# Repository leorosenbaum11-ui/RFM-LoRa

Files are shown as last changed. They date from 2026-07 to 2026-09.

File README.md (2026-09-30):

# RF-Messager-Project
Long range telemetry and communication through LoRa chip WIO-LR2021
PCB in 3d printed case with Keyboard, Screen, 2 SMA Antenna Ports, and GPS FL Antenna port

Part Models (more detailed BOM in files):
Microcontroller: Adafruit Feather ESP32-S3
Pin Extender: MCU23S17
Transciever: Seeed WIO-LR2021
Keyboard Driver: STM32F042CFU(x)
Keyboard: Solderparty Keebdeck Keyboard_6R13C
GPS: Adafruit Ultimate GPS MTK3339
Sensors: TI TMP-100 Temperature, MAX17048 Battery, BME280 Pressure Humidity
Compass: LSM303AGR Compass Accelerometer
Screen: ILI9341 Non-Touch

Program:
upload bbq10 firmware to stm32 and configure
upload my firmware

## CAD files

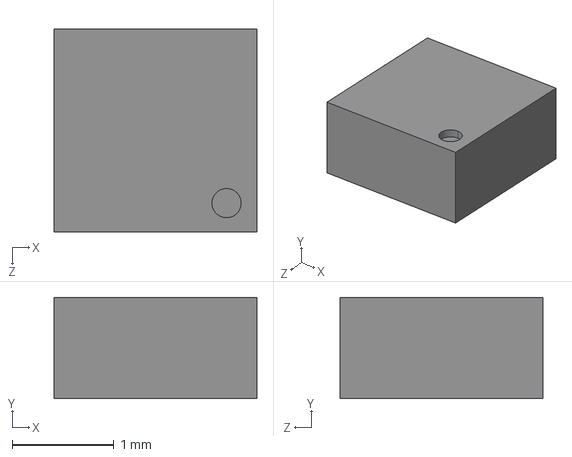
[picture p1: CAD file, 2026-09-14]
PCB Files/Footprint and Symbol Library/LSM303AGR/LSM303AGR.step
2.00 x 1.00 x 2.00 mm

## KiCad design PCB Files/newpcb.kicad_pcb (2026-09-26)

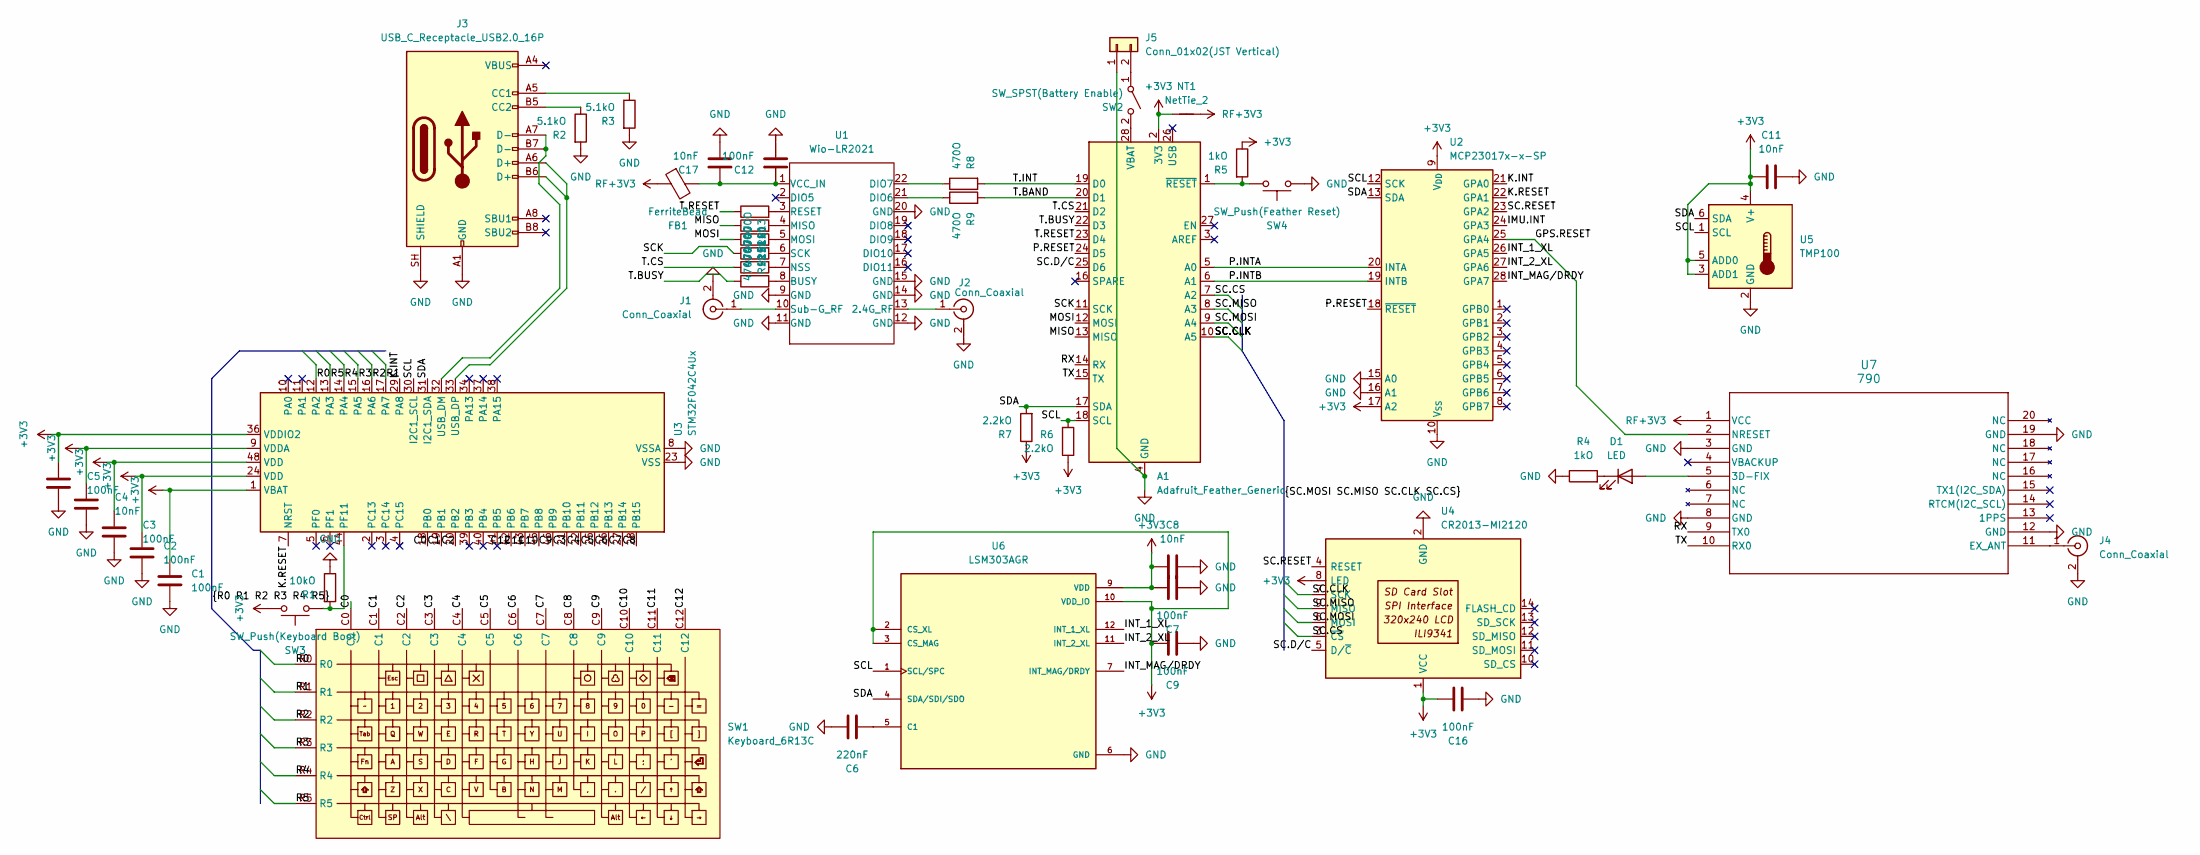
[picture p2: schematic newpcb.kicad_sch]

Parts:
A1: Adafruit_Feather_Generic; Adafruit_Feather
C1, C2, C3, C5, C7, C9, C12, C16: 100nF; C_0603_1608Metric_Pad1.08x0.95mm_HandSolder
C4, C8, C11, C17: 10nF; C_0603_1608Metric_Pad1.08x0.95mm_HandSolder
C6: 220nF; C_0603_1608Metric_Pad1.08x0.95mm_HandSolder
D1: LED; LED_0603_1608Metric_Pad1.05x0.95mm_HandSolder
FB1: FerriteBead; L_0603_1608Metric_Pad1.05x0.95mm_HandSolder
J1, J2: Conn_Coaxial; SMA_Molex_73251-1153_EdgeMount_Horizontal
J3: USB_C_Receptacle_USB2.0_16P; USB_C_Receptacle_HRO_TYPE-C-31-M-12
J4: Conn_Coaxial; U.FL_Molex_MCRF_73412-0110_Vertical
J5: Conn_01x02(JST Vertical); JST_PH_B2B-PH-K_1x02_P2.00mm_Vertical
NT1: NetTie_2; NetTie-2_SMD_Pad2.0mm
R1: 10kO; R_0603_1608Metric_Pad0.98x0.95mm_HandSolder
R2, R3: 5.1kO; R_0603_1608Metric_Pad0.98x0.95mm_HandSolder
R4, R5: 1kO; R_0603_1608Metric_Pad0.98x0.95mm_HandSolder
R6, R7: 2.2kO; R_0603_1608Metric_Pad0.98x0.95mm_HandSolder
R8, R9, R10, R11, R12, R13, R14, R15: 470O; R_0603_1608Metric_Pad0.98x0.95mm_HandSolder
SW1: Keyboard_6R13C
SW2: SW_SPST(Battery Enable); SW_DIP_SPSTx01_Slide_6.7x4.1mm_W6.73mm_P2.54mm_LowProfile_J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
SW3: SW_Push(Keyboard Boot); SW_Push_1TS009xxxx-xxxx-xxxx_6x6x5mm
SW4: SW_Push(Feather Reset); SW_Push_1TS009xxxx-xxxx-xxxx_6x6x5mm
U1: Wio-LR2021; Wio-LR2021_V1
U2: MCP23017x-x-SP; DIP-28_W7.62mm
U3: STM32F042C4Ux; QFN-48-1EP_7x7mm_P0.5mm_EP5.6x5.6mm
U4: CR2013-MI2120
U5: TMP100; SOT-23-6
U6: LSM303AGR; PQFN50P200X200X100-12N; PARTREV 10
U7: 790; PA1616S_ADA

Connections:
+3V3: A1.2 (3V3), C1.1, C2.1, C3.1, C4.1, C5.1, C7.1, C8.1, C9.1, C11.1, C16.1, NT1.1, R5.1, R6.1, R7.1, SW3.1, U2.9 (V_{DD}), U2.17 (A2), U3.1 (VBAT), U3.9 (VDDA), U3.24 (VDD), U3.36 (VDDIO2), U3.48 (VDD), U4.1 (VCC), U4.8 (LED), U5.3 (ADD1), U5.4 (V+), U5.5 (ADD0), U6.2 (CS_XL), U6.3 (CS_MAG), U6.9 (VDD), U6.10 (VDD_IO)
/C0: SW1.C0, U3.18 (PB0)
/C1: SW1.C1, U3.19 (PB1)
/C2: SW1.C2, U3.20 (PB2)
/C3: SW1.C3, U3.21 (PB10)
/C4: SW1.C4, U3.22 (PB11)
/C5: SW1.C5, U3.25 (PB12)
/C6: SW1.C6, U3.26 (PB13)
/C7: SW1.C7, U3.27 (PB14)
/C8: SW1.C8, U3.28 (PB15)
/C9: SW1.C9, U3.46 (PB9)
/C10: SW1.C10, U3.45 (PB8)
/C11: SW1.C11, U3.43 (PB7)
/C12: SW1.C12, U3.42 (PB6)
/GPS.RESET: U2.25 (GPA4), U7.2 (NRESET)
/IMU.INT: U2.24 (GPA3)
/INT_1_XL: U2.26 (GPA5), U6.12 (INT_1_XL)
/INT_2_XL: U2.27 (GPA6), U6.11 (INT_2_XL)
/INT_MAG/DRDY: U2.28 (GPA7), U6.7 (INT_MAG/DRDY)
/K.INT: U2.21 (GPA0), U3.29 (PA8)
/K.RESET: U2.22 (GPA1), U3.7 (NRST)
/MISO: A1.13 (MISO), R11.1
/MOSI: A1.12 (MOSI), R12.1
/P.INTA: A1.5 (A0), U2.20 (INTA)
/P.INTB: A1.6 (A1), U2.19 (INTB)
/P.RESET: A1.24 (D5), U2.18 (~RESET)
/R0: SW1.R0, U3.12 (PA2)
/R1: SW1.R1, U3.17 (PA7)
/R2: SW1.R2, U3.16 (PA6)
/R3: SW1.R3, U3.15 (PA5)
/R4: SW1.R4, U3.14 (PA4)
/R5: SW1.R5, U3.13 (PA3)
/RX: A1.14 (RX), U7.9 (TX0)
/SC.CLK: A1.10 (A5), U4.7 (SCK)
/SC.CS: A1.7 (A2), U4.3 (~CS)
/SC.D/C: A1.25 (D6), U4.5 (D/~C)
/SC.MISO: A1.8 (A3), U4.9 (MISO)
/SC.MOSI: A1.9 (A4), U4.6 (MOSI)
/SC.RESET: U2.23 (GPA2), U4.4 (RESET)
/SCK: A1.11 (SCK), R13.1
/SCL: A1.18 (SCL), R6.2, U2.12 (SCK), U3.30 (I2C1_SCL), U5.1 (SCL), U6.1 (SCL/SPC)
/SDA: A1.17 (SDA), R7.2, U2.13 (SDA), U3.31 (I2C1_SDA), U5.6 (SDA), U6.4 (SDA/SDI/SDO)
/T.BAND: A1.20 (D1), R9.2
/T.BUSY: A1.22 (D3), R15.1
/T.CS: A1.21 (D2), R14.1
/T.INT: A1.19 (D0), R8.2
/T.RESET: A1.23 (D4), R10.1
/TX: A1.15 (TX), U7.10 (RX0)
GND: A1.4 (GND), C1.2, C2.2, C3.2, C4.2, C5.2, C6.1, C7.2, C8.2, C9.2, C11.2, C12.2, C16.2, C17.2, J1.2 (Ext), J2.2 (Ext), J3.A1 (GND), J3.A12 (GND), J3.B1 (GND), J3.B12 (GND), J3.SH (SHIELD), J4.2 (Ext), J5.1, R1.1, R2.2, R3.2, R4.1, SW4.2, U1.9 (GND), U1.11 (GND), U1.12 (GND), U1.14 (GND), U1.15 (GND), U1.20 (GND), U2.10 (V_{SS}), U2.15 (A0), U2.16 (A1), U3.8 (VSSA), U3.23 (VSS), U3.35 (VSS), U3.47 (VSS), U3.49 (VSS), U4.2 (GND), U5.2 (GND), U6.6 (GND), U6.8 (GND), U7.3 (GND), U7.8 (GND), U7.12 (GND), U7.19 (GND)
unnamed: A1.28 (VBAT), SW2.2 (B)
unnamed: A1.1 (~RESET), R5.2, SW4.1
unnamed: D1.2 (A), U7.5 (3D-FIX)
unnamed: D1.1 (K), R4.2
unnamed: J1.1 (In), U1.10 (Sub-G_RF)
unnamed: J2.1 (In), U1.13 (2.4G_RF)
unnamed: J3.A5 (CC1), R3.1
unnamed: J3.B5 (CC2), R2.1
unnamed: J4.1 (In), U7.11 (EX_ANT)
unnamed: J5.2, SW2.1 (A)
unnamed: R15.2, U1.8 (BUSY)
unnamed: R9.1, U1.21 (DIO6)
unnamed: R8.1, U1.22 (DIO7)
unnamed: R11.2, U1.4 (MISO)
unnamed: R12.2, U1.5 (MOSI)
unnamed: R14.2, U1.7 (NSS)
unnamed: R10.2, U1.3 (RESET)
unnamed: R13.2, U1.6 (SCK)
unnamed: C12.1, C17.1, FB1.2, U1.1 (VCC_IN)
unnamed: J3.A7 (D-), J3.B7 (D-), U3.32 (USB_DM)
unnamed: J3.A6 (D+), J3.B6 (D+), U3.33 (USB_DP)
unnamed: R1.2, SW3.2, U3.44 (PF11)
unnamed: C6.2, U6.5 (C1)
RF+3V3: FB1.1, NT1.2, U7.1 (VCC)

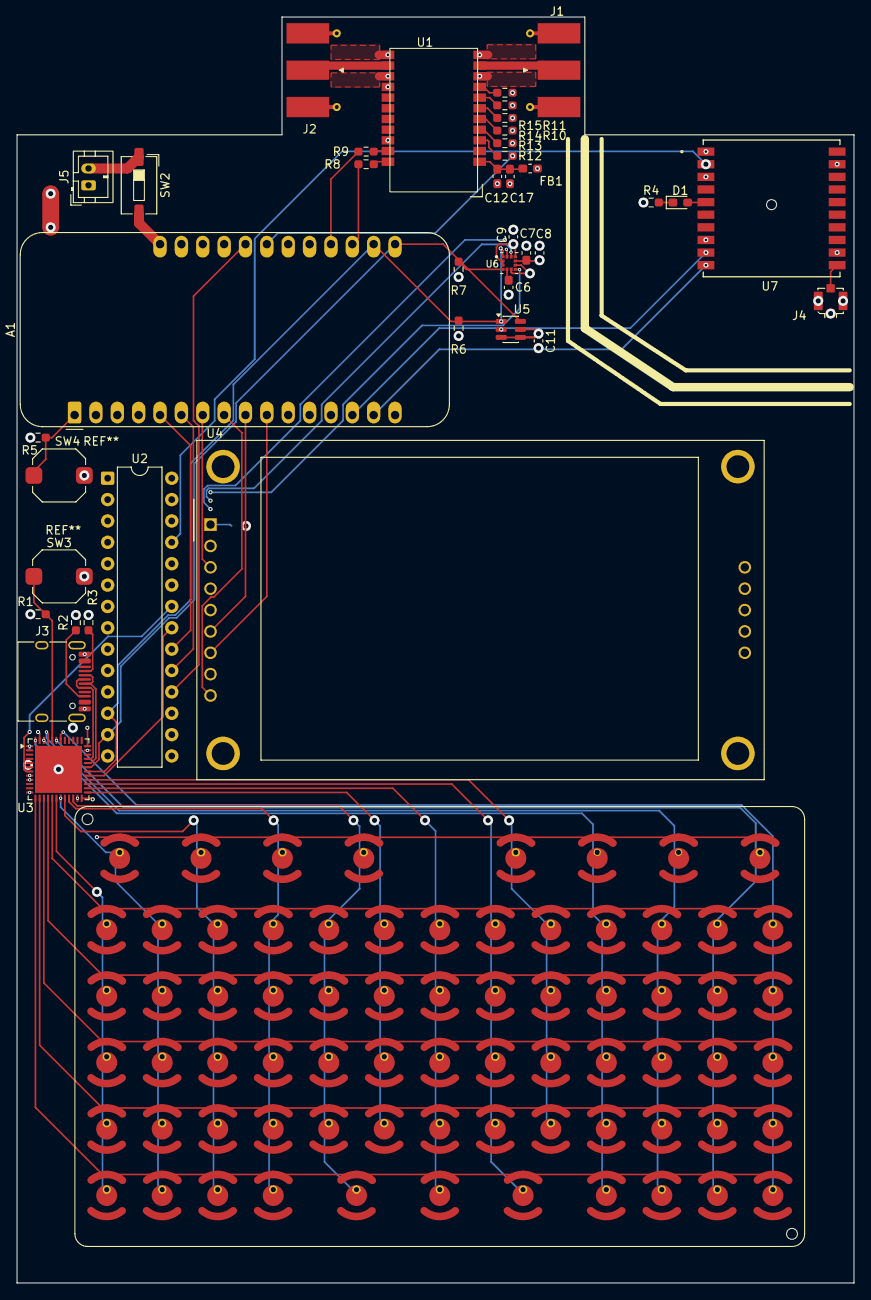
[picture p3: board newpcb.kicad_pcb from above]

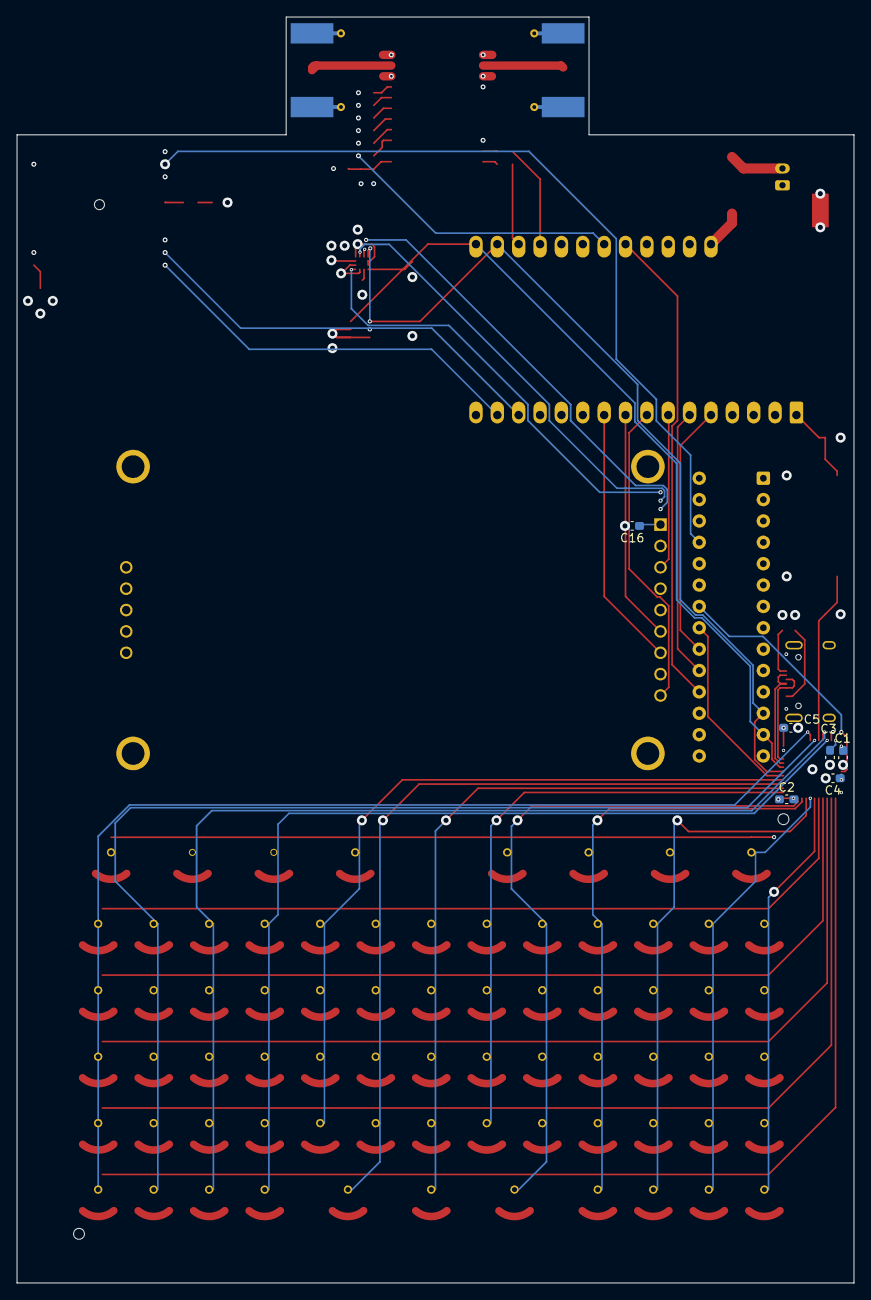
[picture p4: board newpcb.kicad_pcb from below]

Board: 4 copper layers, 99.5 x 150.5 mm, 48 parts (6 on the bottom side), 72 nets.

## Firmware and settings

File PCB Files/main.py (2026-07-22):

import machine
import time
import _thread
from machine import Timer

#pins
txser = machine.Pin(17, machine.Pin.OUT)
rxser = machine.Pin(16, machine.Pin.IN)
intled = machine.Pin(25, machine.Pin.OUT)

#backside/transcieving
class Individual:
    header = "101010101011"
    header_tuple = ["1", "0", "1", "0", "1", "0", "1", "0", "1", "0", "1", "1"]
    
    def __init__(self, footprint, bit_duration):
        self.bit_duration = bit_duration
        self.samplerate = (1000000 // self.bit_duration) * 8
        self.tx = Transmitter(footprint, self)
        self.rx = Receiver(footprint, self)
        self.message = ""
        self.txMsg = ""
        
    def stopRx(self):
        self.rx.stopclock()
        self.bit_buffer = []
        self.ticks = 0
        self.synced = False
        self.sampled = False
        self.prev_val = rxser.value()
        
    def decodeLoop_core1(self):
        #to run on core 1
        while True:
            if self.rx.dataReady:
                self.rx.decode(self.rx.bit_buffer)
                
                if self.message.endswith("led on "):
                    intled.high()
                elif self.message.endswith("led off "):
                    intled.low()
                    
                time.sleep_us(int(self.bit_duration // 12.5))
                print("recieved: ", self.message)
                print("----------------------------------------")
        
    def startTx(self, msg):
        txser.low()
        self.txMsg = msg
        
        txser.high()
        time.sleep_us(self.bit_duration * 2)
        txser.low()
        time.sleep_us(self.bit_duration * 2)
                
        self.tx.transmit(self.tx.encode(" "))
        time.sleep_us(int(self.bit_duration * 2.6))
        self.tx.transmit(self.tx.encode(" "))
        time.sleep_us(int(self.bit_duration * 2.6))
        
        for char in tuple(self.txMsg):
            self.tx.transmit(self.tx.encode(char))
            print(char, " has been sent with footprint: ", self.tx.footprint)
            time.sleep_us(int(self.bit_duration * 2.6))
        self.tx.transmit(self.tx.encode(" "))
        time.sleep_us(int(self.bit_duration * 2.6))
        

class Transmitter:
    def __init__(self, footprint, parent):
        self.footprint = footprint #identification
        self.parent = parent
        
    def encode(self, char):
        #content
        charbin = f"{ord(char):08b}"
        content = "".join([self.footprint, charbin])
        
        #encoding
        manchester = "".join({"0": "01", "1": "10"}[b] for b in content)
        finaltransmit = "".join([Individual.header, manchester])
        
        return finaltransmit
    
    def transmit(self, code):
        for pulse in code:
            if pulse == "1":
                txser.high()
            else:
                txser.low()
            time.sleep_us(self.parent.bit_duration//2)
        txser.low()

class Receiver:
    def __init__(self, footprint, parent):
        #id and clock
        self.footprint = footprint #identification
        self.tim = Timer(-1)
        self.parent = parent
        
        #isr
        self.ticks = 0
        self.prev_val = rxser.value()
        self.bit_buffer = []
        
        #flags
        self.sampled = False #check if sampled each bit
        self.synced = False #check if locked to a transmission through header
        self.dataReady = False #check if transmission finished
        
        #decoding
        self.string_buffer = ""
        
    def _callback(self, t):
        #cant allocate memory for arrays or do cpu intense in here, because it happens 800hz and GC will mess stuff up
        current_val = rxser.value()
        
        #clock recovery, reset ticks at middle of bit
        if current_val != self.prev_val:
            if self.ticks > 6:
                #print("transition detected at tick: ", self.ticks, ", current_val at 75% of previous bit: ", current_val)
                self.ticks = 0
                self.sampled = False
            self.prev_val = current_val
        
        self.ticks += 1
        
        #unsynced header check
        if self.ticks == 2 and not self.synced or self.ticks == 6 and not self.synced:
            bit = "0" if current_val == 0 else "1"
            self.bit_buffer.append(bit)
            
            if len(self.bit_buffer) >= 12:
                match = True
                for i in range(12):
                    if self.bit_buffer[-12 + i] != Individual.header_tuple[i]:
                        match = False
                        break
                
                if match:
                    print("matched onto header")
                    print(self.bit_buffer)
                    self.synced = True
                    self.bit_buffer = []
        
        #synced data storage
        if self.synced:
            if self.ticks == 2 and not self.sampled:
                bit = "1" if current_val == 0 else "0"
                self.bit_buffer.append(bit)
                self.sampled = True
            
        if self.ticks > 16 and self.prev_val == current_val and self.synced and len(self.bit_buffer) >= len(self.footprint) + 8 and not self.dataReady:
            self.dataReady = True
    
    def start(self):
        #starts listening for header(self.synced)
        self.sampled = False
        self.bit_buffer = []
        self.ticks = 0
        self.synced = False
        self.tim.init(freq=self.parent.samplerate, mode=Timer.PERIODIC, callback=self._callback)
        self.prev_val = rxser.value()
        
    def stopclock(self):
        self.tim.deinit()
        time.sleep_ms(100)

    
    def decode(self, buffer):
        if self.dataReady:
            self.ticks = 0
            self.synced = False
            
            #convert to string and clear bit_buffer
            self.string_buffer = "".join(self.bit_buffer)
            print(self.string_buffer)
            self.bit_buffer = []
            
            #flags
            self.dataReady = False
            self.synced = False
            self.sampled = False
            self.ticks = 0
            
            if self.string_buffer[0:len(self.footprint)] == self.footprint:
                self.parent.message += chr(int(self.string_buffer[len(self.footprint):len(self.footprint) + 8], 2))
            else:
                print("unmatching footprint")
            
            self.dataReady = False

#loopback
intled.low()
heydude = Individual("110110", 5000)

heydude.rx.start()
_thread.start_new_thread(heydude.decodeLoop_core1, ())

while True:
    heydude.startTx(input("sending: "))

#9459940614

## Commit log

2026-07-22 rearrange and add files in preparation for new lora and other stuff
    [newpcb.kicad_pcb, newpcb.kicad_sch]
2026-07-29 Redid Schematic Entirely
    Now have LORA tech, feather controller, many sensors, keyboard and screen. entire project revamped. need to do software next.
    [newpcb.kicad_sch]
2026-08-20 Updated PCB, worked on radio section, positioned chips and stuff on board
    [newpcb.kicad_pcb, newpcb.kicad_sch]
2026-09-09 Finished keyboard controller matrix, did some wiring
    [newpcb.kicad_pcb, newpcb.kicad_sch]
2026-09-14 Add compass(magnetometer) and accelerometer footprint files
    [LSM303AGR.step]
2026-09-14 Add compass(magnetometer) and accelerometer (#2 in folder)
    [LSM303AGR.step]
2026-09-17 Update I2C Addresses for new compass and accelerometer
    Replaced MPU9150 address with LSM303AGR addresses.
2026-09-18 Finish PCB, yay
    [newpcb.kicad_pcb, newpcb.kicad_sch]
2026-09-26 fix error in gps uart
    [newpcb.kicad_pcb, newpcb.kicad_sch]
2026-09-26 Added code environment
    [newpcb.kicad_pcb]
2026-11-06 fixes regarding uart
